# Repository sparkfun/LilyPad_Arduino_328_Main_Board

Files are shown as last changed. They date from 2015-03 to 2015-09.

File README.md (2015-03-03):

SparkFun LilyPad Arduino 328 Main Board
=======================================
SparkFun LilyPad Arduino 328 Main Board

[*SparkFun LilyPad Arduino 328 Main Board
 (DEV-09266)*](https://www.sparkfun.com/products/9266)

This is LilyPad Arduino - the main board consisting of an ATmega328 with the Arduino bootloader and a minimum number of external components to keep it as small (and as simple) as possible. Board will run from 2V to 5V. 

Repository Contents
-------------------

* **/Hardware** - All Eagle design files (.brd, .sch)
License Information
-------------------
The hardware is released under [Creative Commons ShareAlike 4.0 International](https://creativecommons.org/licenses/by-sa/4.0/).

Distributed as-is; no warranty is given.

_A portion of this sale is given back to Dr. Leah Buechley for continued development and education of e-textiles and also to Arduino LLC to help fund continued development of new tools and new IDE features._

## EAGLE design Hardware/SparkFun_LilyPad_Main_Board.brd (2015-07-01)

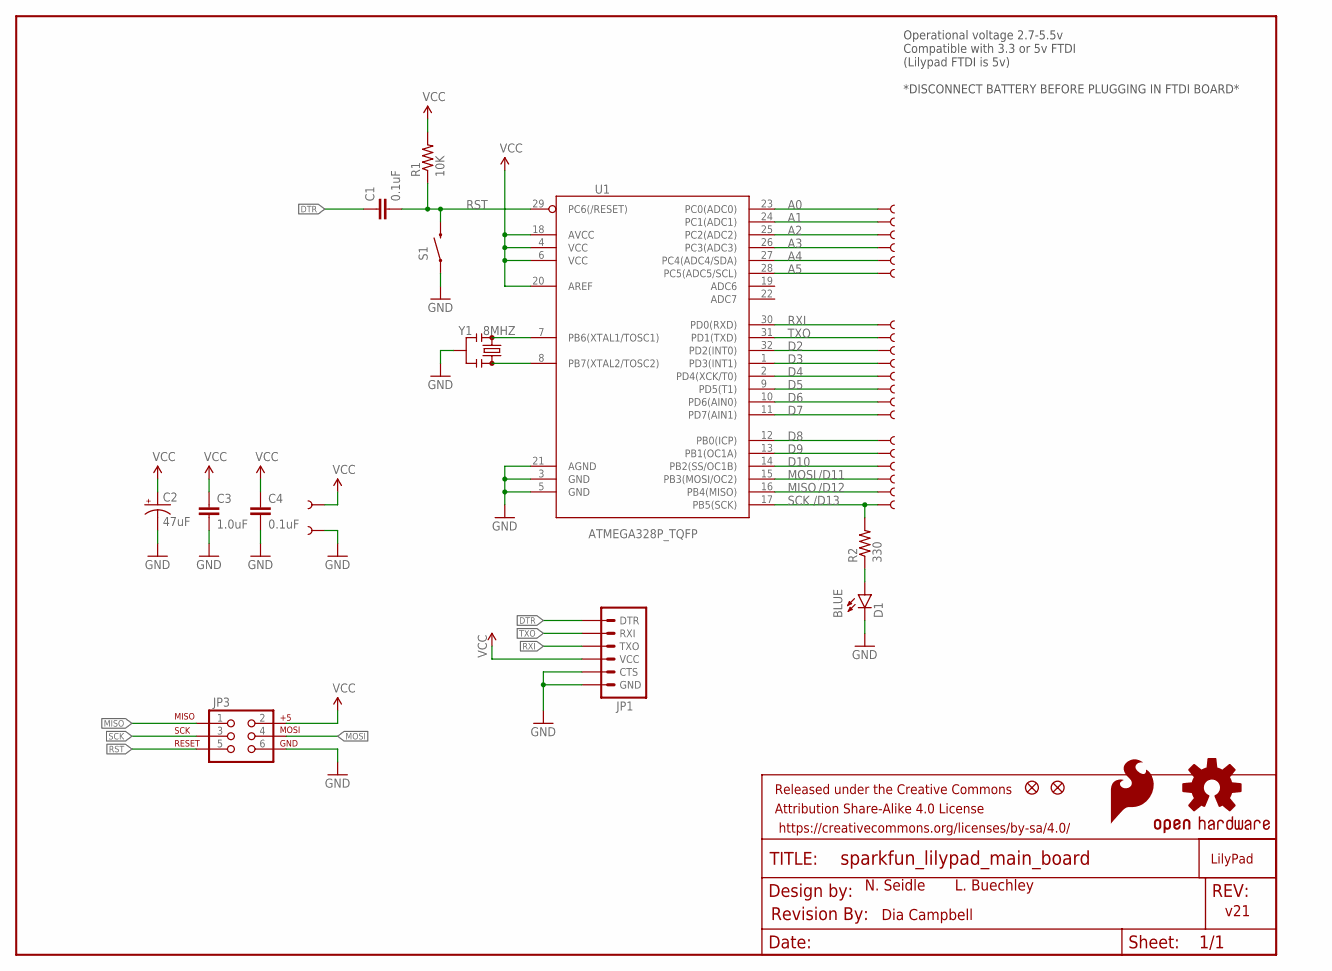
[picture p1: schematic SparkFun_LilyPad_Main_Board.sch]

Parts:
$0000003: LOGO-LPLPA; LOGO-LPA
C1, C4: 0.1uF; 0603-CAP
C2: 47uF; EIA3528
C3: 1.0uF; 0603-CAP
D1: BLUE; LED-0603
FID1, FID2: FIDUCIALUFIDUCIAL; MICRO-FIDUCIAL
FRAME1: FRAME-LETTER; CREATIVE_COMMONS
GND: SEWTAP9; PETAL-LONG-1-2SIDE
JP1: ARDUINO_SERIAL_PROGRAMSMD; 1X06-SMD
JP3: FEMALE 2x3; 2X3-NS
LOGO1: SFE_LOGO_FLAME.3COP; SFE_LOGO_FLAME_COPPER_.3
LOGO2: OSHW-LOGO-COPPERM; OSHW-LOGO-M
R1: 10K; 0603-RES
R2: 330; 0603-RES
S1: SWITCH-MOMENTARY-2SMD-REDUNDANT; TACTILE-SWITCH-SMD
U1: ATMEGA328P_TQFP; TQFP32-08
U$1, U$2, U$3, U$4, U$5, U$6, U$7, U$8, U$9, U$10, U$11, U$12, U$13, U$14, U$15, U$16, U$17, U$18, U$19, U$20, U$21: SEWTAP9; PETAL-LONG-1-2SIDE
U$22: REVISION
Y1: 8MHZ; RESONATOR-SMD

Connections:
A0: U1.23 (PC0(ADC0)), U$1.1
A1: U1.24 (PC1(ADC1)), U$2.1
A2: U1.25 (PC2(ADC2)), U$3.1
A3: U1.26 (PC3(ADC3)), U$4.1
A4: U1.27 (PC4(ADC4/SDA)), U$5.1
A5: U1.28 (PC5(ADC5/SCL)), U$6.1
D2: U1.32 (PD2(INT0)), U$9.1
D3: U1.1 (PD3(INT1)), U$10.1
D4: U1.2 (PD4(XCK/T0)), U$11.1
D5: U1.9 (PD5(T1)), U$12.1
D6: U1.10 (PD6(AIN0)), U$13.1
D7: U1.11 (PD7(AIN1)), U$14.1
D8: U1.12 (PB0(ICP)), U$15.1
D9: U1.13 (PB1(OC1A)), U$16.1
D10: U1.14 (PB2(SS/OC1B)), U$17.1
DTR: C1.1, JP1.1 (DTR)
GND: C2.C (-), C3.2, C4.2, D1.C, GND.1, JP1.5 (CTS), JP1.6 (GND), JP3.6, S1.1, S1.2 (1), U1.3 (GND), U1.5 (GND), U1.21 (AGND), Y1.2
MISO: JP3.1, U1.16 (PB4(MISO)), U$19.1
MOSI: JP3.4, U1.15 (PB3(MOSI/OC2)), U$18.1
unnamed: U1.7 (PB6(XTAL1/TOSC1)), Y1.1
unnamed: D1.A, R2.1
unnamed: U1.8 (PB7(XTAL2/TOSC2)), Y1.3
RST: C1.2, JP3.5, R1.1, S1.3 (2), S1.4 (2), U1.29 (PC6(/RESET))
RXI: JP1.3 (TXO), U1.30 (PD0(RXD)), U$7.1
SCK: JP3.3, R2.2, U1.17 (PB5(SCK)), U$21.1
TXO: JP1.2 (RXI), U1.31 (PD1(TXD)), U$8.1
VCC: C2.A (+), C3.1, C4.1, JP1.4 (VCC), JP3.2, R1.2, U1.4 (VCC), U1.6 (VCC), U1.18 (AVCC), U1.20 (AREF), U$20.1

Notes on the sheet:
/D11
/D12
/D13
L. Buechley
N. Seidle
Dia Campbell
v21
Operational voltage 2.7-5.5v Compatible with 3.3 or 5v FTDI (Lilypad FTDI is 5v) *DISCONNECT BATTERY BEFORE PLUGGING IN FTDI BOARD*

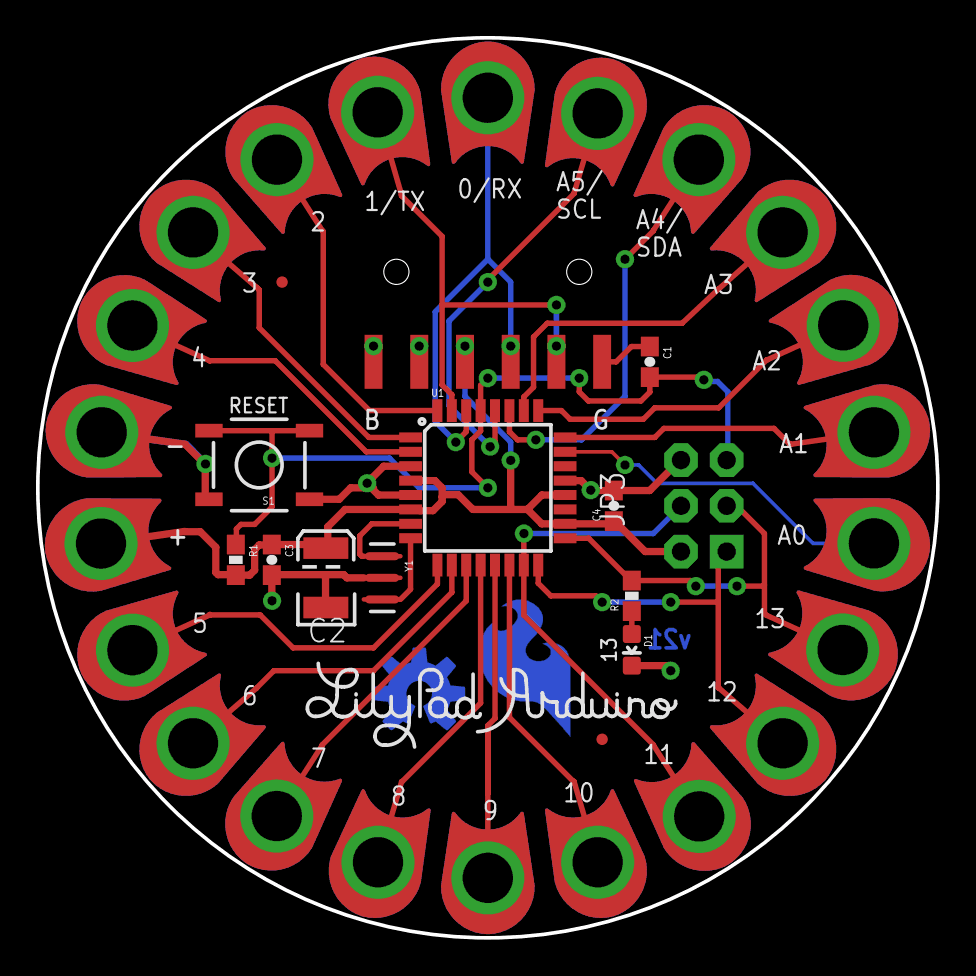
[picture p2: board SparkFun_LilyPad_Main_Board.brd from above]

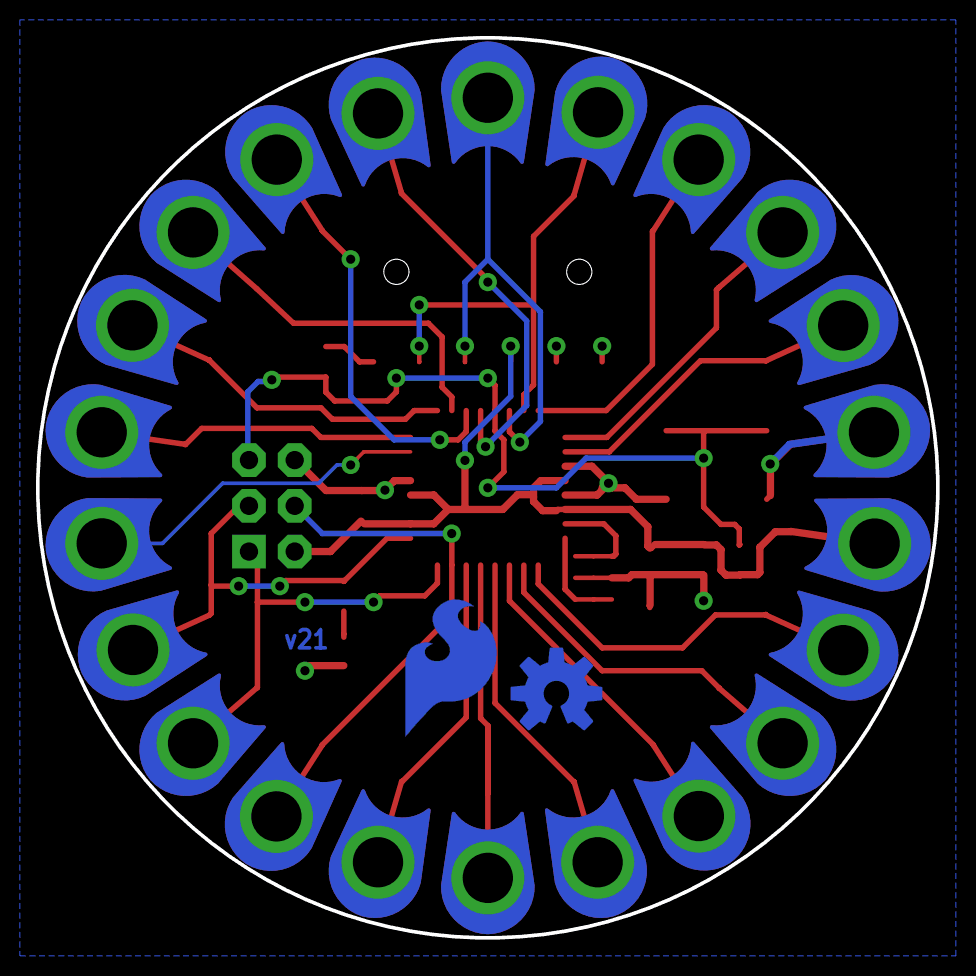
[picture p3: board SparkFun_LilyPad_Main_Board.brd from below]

Board: 2 copper layers, 50.0 x 50.0 mm, 41 parts (2 on the bottom side), 27 nets.

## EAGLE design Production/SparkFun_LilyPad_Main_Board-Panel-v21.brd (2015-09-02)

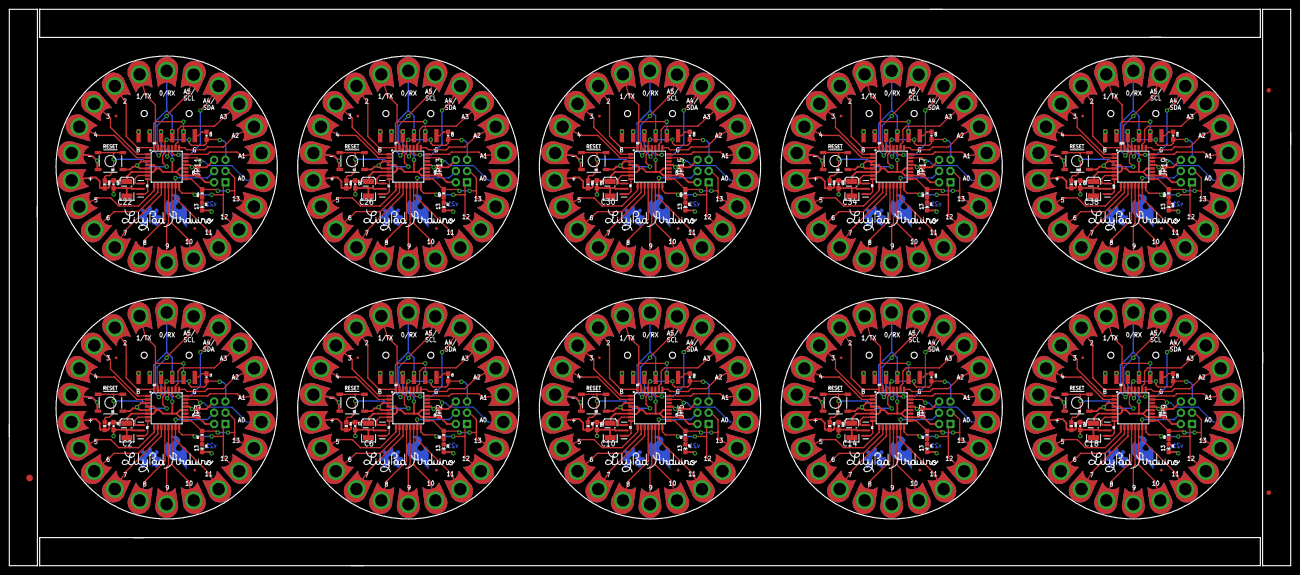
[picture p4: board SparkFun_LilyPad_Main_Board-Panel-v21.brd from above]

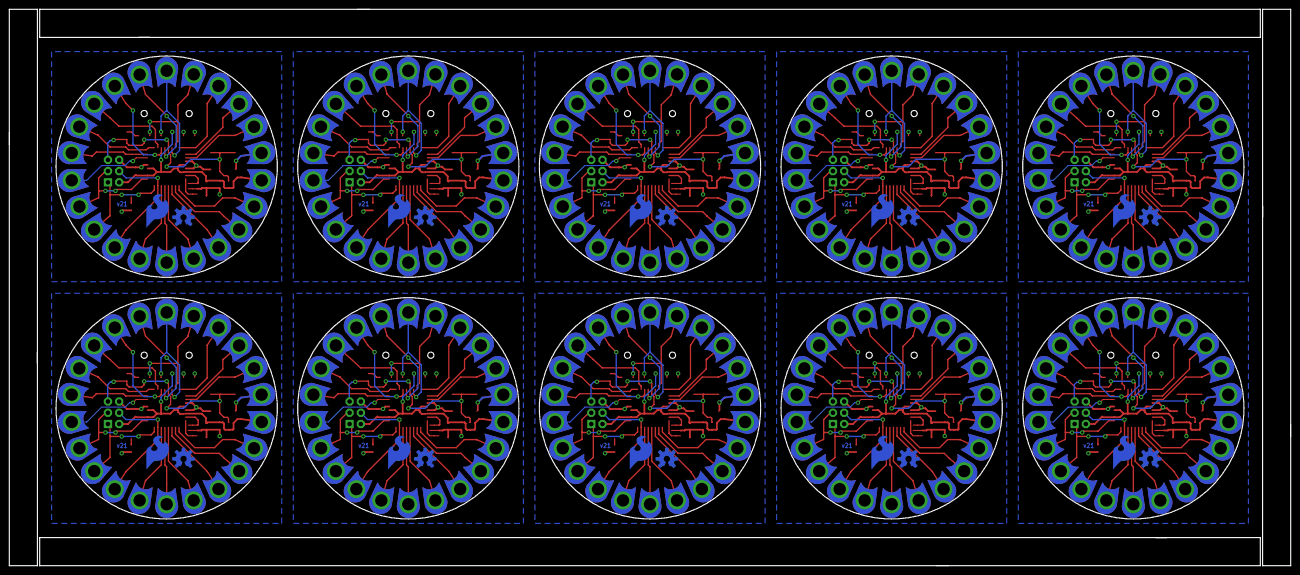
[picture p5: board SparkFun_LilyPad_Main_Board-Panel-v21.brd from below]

Board: 2 copper layers, 289.6 x 125.7 mm, 393 parts (20 on the bottom side), 270 nets.

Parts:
$0000001, $0000002, $0000003, $0000004, $0000005, $0000006, $0000007, $0000008, $0000009, $0000010: LOGO-LPLPA; LOGO-LPA
C1, C4, C5, C8, C9, C12, C13, C16, C17, C20, C21, C24, C25, C28, C29, C32, C33, C36, C37, C40: 0.1uF; 0603-CAP
C2, C6, C10, C14, C18, C22, C26, C30, C34, C38: 47uF; EIA3528
C3, C7, C11, C15, C19, C23, C27, C31, C35, C39: 1.0uF; 0603-CAP
D1, D2, D3, D4, D5, D6, D7, D8, D9, D10: BLUE; LED-0603
E$1: FIDUCIAL-1.5X3
E$7, E$8: FIDUCIAL-1X2
FID1, FID2, FID3, FID4, FID5, FID6, FID7, FID8, FID9, FID10, FID11, FID12, FID13, FID14, FID15, FID16, FID17, FID18, FID19, FID20: FIDUCIALUFIDUCIAL; MICRO-FIDUCIAL
GND, GND1, GND2, GND3, GND4, GND5, GND6, GND7, GND8, GND9: SEWTAP9; PETAL-LONG-1-2SIDE
JP1, JP4, JP6, JP8, JP10, JP12, JP14, JP16, JP18, JP20: 1X06-SMD
JP2, JP3, JP5, JP7, JP9, JP11, JP13, JP15, JP17, JP19: FEMALE 2x3; 2X3-NS
LOGO1, LOGO3, LOGO5, LOGO7, LOGO9, LOGO11, LOGO13, LOGO15, LOGO17, LOGO19: SFE_LOGO_FLAME.3COP; SFE_LOGO_FLAME_COPPER_.3
LOGO2, LOGO4, LOGO6, LOGO8, LOGO10, LOGO12, LOGO14, LOGO16, LOGO18, LOGO20: OSHW-LOGO-COPPERM; OSHW-LOGO-M
R1, R4, R6, R8, R10, R12, R14, R16, R18, R20: 10K; 0603-RES
R2, R3, R5, R7, R9, R11, R13, R15, R17, R19: 330; 0603-RES
S1, S2, S3, S4, S5, S6, S7, S8, S9, S10: SWITCH-MOMENTARY-2SMD-REDUNDANT; TACTILE-SWITCH-SMD
U1, U2, U3, U4, U5, U6, U7, U8, U9, U10: ATMEGA328P_TQFP; TQFP32-08
U$1, U$2, U$3, U$4, U$5, U$6, U$7, U$8, U$9, U$10, U$11, U$12, U$13, U$14, U$15, U$16, U$17, U$18, U$19, U$20, U$21, U$22, U$23, U$24, U$25, U$26, U$27, U$28, U$29, U$30, U$31, U$32, U$33, U$34, U$35, U$36, U$37, U$38, U$39, U$40, U$41, U$42, U$43, U$44, U$45, U$46, U$47, U$48, U$49, U$50, U$51, U$52, U$53, U$54, U$55, U$56, U$57, U$58, U$59, U$60, U$61, U$62, U$63, U$64, U$65, U$66, U$67, U$68, U$69, U$70, U$71, U$72, U$73, U$74, U$75, U$76, U$77, U$78, U$79, U$80, U$81, U$82, U$83, U$84, U$85, U$86, U$87, U$88, U$89, U$90, U$91, U$92, U$93, U$94, U$95, U$96, U$97, U$98, U$99, U$100, U$101, U$102, U$103, U$104, U$105, U$106, U$107, U$108, U$109, U$110, U$111, U$112, U$113, U$114, U$115, U$116, U$117, U$118, U$119, U$120, U$121, U$122, U$123, U$124, U$125, U$126, U$127, U$128, U$129, U$130, U$131, U$132, U$133, U$134, U$135, U$136, U$137, U$138, U$139, U$140, U$141, U$142, U$143, U$144, U$145, U$146, U$147, U$148, U$149, U$150, U$151, U$152, U$153, U$154, U$155, U$156, U$157, U$158, U$159, U$160, U$161, U$162, U$163, U$164, U$165, U$166, U$167, U$168, U$169, U$170, U$171, U$172, U$173, U$174, U$175, U$176, U$177, U$178, U$179, U$180, U$181, U$182, U$183, U$184, U$185, U$186, U$187, U$188, U$189, U$190, U$191, U$192, U$193, U$194, U$195, U$196, U$197, U$198, U$199, U$200, U$201, U$202, U$203, U$204, U$205, U$206, U$207, U$208, U$209, U$210: SEWTAP9; PETAL-LONG-1-2SIDE
Y1, Y2, Y3, Y4, Y5, Y6, Y7, Y8, Y9, Y10: 8MHZ; RESONATOR-SMD

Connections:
A0: U1.23, U$1.1
A1: U1.24, U$2.1
A2: U1.25, U$3.1
A3: U1.26, U$4.1
A4: U1.27, U$5.1
A5: U1.28, U$6.1
A6: U2.23, U$42.1
A7: U2.24, U$22.1
A8: U2.25, U$23.1
A9: U2.26, U$24.1
A10: U2.27, U$25.1
A11: U2.28, U$26.1
A12: U3.23, U$63.1
A13: U3.24, U$43.1
A14: U3.25, U$44.1
A15: U3.26, U$45.1
A16: U3.27, U$46.1
A17: U3.28, U$47.1
A18: U4.23, U$84.1
A19: U4.24, U$64.1
A20: U4.25, U$65.1
A21: U4.26, U$66.1
A22: U4.27, U$67.1
A23: U4.28, U$68.1
A24: U5.23, U$105.1
A25: U5.24, U$85.1
A26: U5.25, U$86.1
A27: U5.26, U$87.1
A28: U5.27, U$88.1
A29: U5.28, U$89.1
A30: U6.23, U$126.1
A31: U6.24, U$106.1
A32: U6.25, U$107.1
A33: U6.26, U$108.1
A34: U6.27, U$109.1
A35: U6.28, U$110.1
A36: U7.23, U$147.1
A37: U7.24, U$127.1
A38: U7.25, U$128.1
A39: U7.26, U$129.1
A40: U7.27, U$130.1
A41: U7.28, U$131.1
A42: U8.23, U$168.1
A43: U8.24, U$148.1
A44: U8.25, U$149.1
A45: U8.26, U$150.1
A46: U8.27, U$151.1
A47: U8.28, U$152.1
A48: U9.23, U$189.1
A49: U9.24, U$169.1
A50: U9.25, U$170.1
A51: U9.26, U$171.1
A52: U9.27, U$172.1
A53: U9.28, U$173.1
A54: U10.23, U$210.1
A55: U10.24, U$190.1
A56: U10.25, U$191.1
A57: U10.26, U$192.1
A58: U10.27, U$193.1
A59: U10.28, U$194.1
D1: U2.32, U$37.1
D2: U1.32, U$9.1
D3: U1.1, U$10.1
D4: U1.2, U$11.1
D5: U1.9, U$12.1
D6: U1.10, U$13.1
D7: U1.11, U$14.1
D8: U1.12, U$15.1
D9: U1.13, U$16.1
D10: U1.14, U$17.1
D11: U2.1, U$36.1
D12: U2.2, U$35.1
D13: U2.9, U$34.1
D14: U2.10, U$33.1
D15: U2.12, U$27.1
D16: U2.14, U$29.1
D17: U2.11, U$40.1
D18: U2.13, U$28.1
D19: U3.32, U$58.1
D20: U3.1, U$57.1
D21: U3.2, U$56.1
D22: U3.9, U$55.1
D23: U3.10, U$54.1
D24: U3.12, U$48.1
D25: U3.14, U$50.1
D26: U3.11, U$61.1
D27: U3.13, U$49.1
D28: U4.32, U$79.1
D29: U4.1, U$78.1
D30: U4.2, U$77.1
D31: U4.9, U$76.1
D32: U4.10, U$75.1
D33: U4.12, U$69.1
D34: U4.14, U$71.1
D35: U4.11, U$82.1
D36: U4.13, U$70.1
D37: U5.32, U$100.1
D38: U5.1, U$99.1
D39: U5.2, U$98.1
D40: U5.9, U$97.1
D41: U5.10, U$96.1
D42: U5.12, U$90.1
D43: U5.14, U$92.1
D44: U5.11, U$103.1
D45: U5.13, U$91.1
D46: U6.32, U$121.1
D47: U6.1, U$120.1
D48: U6.2, U$119.1
D49: U6.9, U$118.1
D50: U6.10, U$117.1
D51: U6.12, U$111.1
D52: U6.14, U$113.1
D53: U6.11, U$124.1
D54: U6.13, U$112.1
D55: U7.32, U$142.1
D56: U7.1, U$141.1
D57: U7.2, U$140.1
D58: U7.9, U$139.1
D59: U7.10, U$138.1
D60: U7.12, U$132.1
D61: U7.14, U$134.1
D62: U7.11, U$145.1
D63: U7.13, U$133.1
D64: U8.32, U$163.1
D65: U8.1, U$162.1
D66: U8.2, U$161.1
D67: U8.9, U$160.1
D68: U8.10, U$159.1
D69: U8.12, U$153.1
D70: U8.14, U$155.1
D71: U8.11, U$166.1
D72: U8.13, U$154.1
D73: U9.32, U$184.1
D74: U9.1, U$183.1
D75: U9.2, U$182.1
D76: U9.9, U$181.1
D77: U9.10, U$180.1
D78: U9.12, U$174.1
D79: U9.14, U$176.1
D80: U9.11, U$187.1
D81: U9.13, U$175.1
D82: U10.32, U$205.1
D83: U10.1, U$204.1
D84: U10.2, U$203.1
D85: U10.9, U$202.1
D86: U10.10, U$201.1
D87: U10.12, U$195.1
D88: U10.14, U$197.1
D89: U10.11, U$208.1
D90: U10.13, U$196.1
DTR: C1.1, JP1.1
DTR1: C8.1, JP4.1
DTR2: C12.1, JP6.1
DTR3: C16.1, JP8.1
DTR4: C20.1, JP10.1
DTR5: C24.1, JP12.1
DTR6: C28.1, JP14.1
DTR7: C32.1, JP16.1
DTR8: C36.1, JP18.1
DTR9: C40.1, JP20.1
GND: C2.C, C3.2, C4.2, D1.C, GND.1, JP1.5, JP1.6, JP3.6, S1.1, S1.2, U1.3, U1.5, U1.21, Y1.2
GND1: C5.2, C6.C, C7.2, D2.C, GND1.1, JP2.6, JP4.5, JP4.6, S2.1, S2.2, U2.3, U2.5, U2.21, Y2.2
GND2: C9.2, C10.C, C11.2, D3.C, GND2.1, JP5.6, JP6.5, JP6.6, S3.1, S3.2, U3.3, U3.5, U3.21, Y3.2
GND3: C13.2, C14.C, C15.2, D4.C, GND3.1, JP7.6, JP8.5, JP8.6, S4.1, S4.2, U4.3, U4.5, U4.21, Y4.2
GND4: C17.2, C18.C, C19.2, D5.C, GND4.1, JP9.6, JP10.5, JP10.6, S5.1, S5.2, U5.3, U5.5, U5.21, Y5.2
GND5: C21.2, C22.C, C23.2, D6.C, GND5.1, JP11.6, JP12.5, JP12.6, S6.1, S6.2, U6.3, U6.5, U6.21, Y6.2
GND6: C25.2, C26.C, C27.2, D7.C, GND6.1, JP13.6, JP14.5, JP14.6, S7.1, S7.2, U7.3, U7.5, U7.21, Y7.2
GND7: C29.2, C30.C, C31.2, D8.C, GND7.1, JP15.6, JP16.5, JP16.6, S8.1, S8.2, U8.3, U8.5, U8.21, Y8.2
GND8: C33.2, C34.C, C35.2, D9.C, GND8.1, JP17.6, JP18.5, JP18.6, S9.1, S9.2, U9.3, U9.5, U9.21, Y9.2
GND9: C37.2, C38.C, C39.2, D10.C, GND9.1, JP19.6, JP20.5, JP20.6, S10.1, S10.2, U10.3, U10.5, U10.21, Y10.2
MISO: JP3.1, U1.16, U$19.1
MISO1: JP2.1, U2.16, U$31.1
MISO2: JP5.1, U3.16, U$52.1
MISO3: JP7.1, U4.16, U$73.1
MISO4: JP9.1, U5.16, U$94.1
MISO5: JP11.1, U6.16, U$115.1
MISO6: JP13.1, U7.16, U$136.1
MISO7: JP15.1, U8.16, U$157.1
MISO8: JP17.1, U9.16, U$178.1
MISO9: JP19.1, U10.16, U$199.1
MOSI: JP3.4, U1.15, U$18.1
MOSI1: JP2.4, U2.15, U$30.1
MOSI2: JP5.4, U3.15, U$51.1
MOSI3: JP7.4, U4.15, U$72.1
MOSI4: JP9.4, U5.15, U$93.1
MOSI5: JP11.4, U6.15, U$114.1
MOSI6: JP13.4, U7.15, U$135.1
MOSI7: JP15.4, U8.15, U$156.1
MOSI8: JP17.4, U9.15, U$177.1
MOSI9: JP19.4, U10.15, U$198.1
unnamed: U1.7, Y1.1
unnamed: D1.A, R2.1
unnamed: U1.8, Y1.3
unnamed: D2.A, R3.1
unnamed: U2.7, Y2.1
unnamed: U2.8, Y2.3
unnamed: D3.A, R5.1
unnamed: U3.7, Y3.1
unnamed: U3.8, Y3.3
unnamed: D4.A, R7.1
unnamed: U4.7, Y4.1
unnamed: U4.8, Y4.3
unnamed: D5.A, R9.1
unnamed: U5.7, Y5.1
unnamed: U5.8, Y5.3
unnamed: D6.A, R11.1
unnamed: U6.7, Y6.1
unnamed: U6.8, Y6.3
unnamed: D7.A, R13.1
unnamed: U7.7, Y7.1
unnamed: U7.8, Y7.3
unnamed: D8.A, R15.1
unnamed: U8.7, Y8.1
unnamed: U8.8, Y8.3
unnamed: D9.A, R17.1
unnamed: U9.7, Y9.1
unnamed: U9.8, Y9.3
unnamed: D10.A, R19.1
unnamed: U10.7, Y10.1
unnamed: U10.8, Y10.3
RST: C1.2, JP3.5, R1.1, S1.3, S1.4, U1.29
RST1: C8.2, JP2.5, R4.1, S2.3, S2.4, U2.29
RST2: C12.2, JP5.5, R6.1, S3.3, S3.4, U3.29
RST3: C16.2, JP7.5, R8.1, S4.3, S4.4, U4.29
RST4: C20.2, JP9.5, R10.1, S5.3, S5.4, U5.29
RST5: C24.2, JP11.5, R12.1, S6.3, S6.4, U6.29
RST6: C28.2, JP13.5, R14.1, S7.3, S7.4, U7.29
RST7: C32.2, JP15.5, R16.1, S8.3, S8.4, U8.29
RST8: C36.2, JP17.5, R18.1, S9.3, S9.4, U9.29
RST9: C40.2, JP19.5, R20.1, S10.3, S10.4, U10.29
RXI: JP1.3, U1.30, U$7.1
RXI1: JP4.3, U2.30, U$39.1
RXI2: JP6.3, U3.30, U$60.1
RXI3: JP8.3, U4.30, U$81.1
RXI4: JP10.3, U5.30, U$102.1
RXI5: JP12.3, U6.30, U$123.1
RXI6: JP14.3, U7.30, U$144.1
RXI7: JP16.3, U8.30, U$165.1
RXI8: JP18.3, U9.30, U$186.1
RXI9: JP20.3, U10.30, U$207.1
SCK: JP3.3, R2.2, U1.17, U$21.1
SCK1: JP2.3, R3.2, U2.17, U$32.1
SCK2: JP5.3, R5.2, U3.17, U$53.1
SCK3: JP7.3, R7.2, U4.17, U$74.1
SCK4: JP9.3, R9.2, U5.17, U$95.1
SCK5: JP11.3, R11.2, U6.17, U$116.1
SCK6: JP13.3, R13.2, U7.17, U$137.1
SCK7: JP15.3, R15.2, U8.17, U$158.1
SCK8: JP17.3, R17.2, U9.17, U$179.1
SCK9: JP19.3, R19.2, U10.17, U$200.1
TXO: JP1.2, U1.31, U$8.1
TXO1: JP4.2, U2.31, U$38.1
TXO2: JP6.2, U3.31, U$59.1
TXO3: JP8.2, U4.31, U$80.1
TXO4: JP10.2, U5.31, U$101.1
TXO5: JP12.2, U6.31, U$122.1
TXO6: JP14.2, U7.31, U$143.1
TXO7: JP16.2, U8.31, U$164.1
TXO8: JP18.2, U9.31, U$185.1
TXO9: JP20.2, U10.31, U$206.1
VCC: C2.A, C3.1, C4.1, JP1.4, JP3.2, R1.2, U1.4, U1.6, U1.18, U1.20, U$20.1
VCC1: C5.1, C6.A, C7.1, JP2.2, JP4.4, R4.2, U2.4, U2.6, U2.18, U2.20, U$41.1
VCC2: C9.1, C10.A, C11.1, JP5.2, JP6.4, R6.2, U3.4, U3.6, U3.18, U3.20, U$62.1
VCC3: C13.1, C14.A, C15.1, JP7.2, JP8.4, R8.2, U4.4, U4.6, U4.18, U4.20, U$83.1
VCC4: C17.1, C18.A, C19.1, JP9.2, JP10.4, R10.2, U5.4, U5.6, U5.18, U5.20, U$104.1
VCC5: C21.1, C22.A, C23.1, JP11.2, JP12.4, R12.2, U6.4, U6.6, U6.18, U6.20, U$125.1
VCC6: C25.1, C26.A, C27.1, JP13.2, JP14.4, R14.2, U7.4, U7.6, U7.18, U7.20, U$146.1
VCC7: C29.1, C30.A, C31.1, JP15.2, JP16.4, R16.2, U8.4, U8.6, U8.18, U8.20, U$167.1
VCC8: C33.1, C34.A, C35.1, JP17.2, JP18.4, R18.2, U9.4, U9.6, U9.18, U9.20, U$188.1
VCC9: C37.1, C38.A, C39.1, JP19.2, JP20.4, R20.2, U10.4, U10.6, U10.18, U10.20, U$209.1

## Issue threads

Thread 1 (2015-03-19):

Design review v21

lewispg228, 2015-03-19:
1) Remove strange GND polygon under reset button

2) Needs a note about proper VCC range in schematic, and possibly a note about must match which FTDI VCC you are using (3.3V or 5V)

3) Route resonator trace off "upper" pad so that it goes outward, and avoids causing a "T" underneath the part.

4) Needs version number in copper

5) Remove "FEMALE 2X3" value on JP3

6) Better placement of name/value on U1 (in schematic)

7) Move vias on FTDI header pads off of the pads, re-route as necessary

8) Increase trace width on GND and VCC to 16 mil.

9) Our new standard for Stat LEDs is Blue, but this could be an exception if it is deemed to much of a pain point to update documentation.

10) Use GND/VCC symbols coming off of JP1.

11) include measures on layer 47 (maybe just the diameter)

12) Needs fiducials

13) I think it would be worth adding a bottom side trace from the "-" pedal to the ground pour to increase the amount of copper connecting to GND. As it is now, there is really only a single 12 mil trace returning all current form the board to GND.

14) Needs note on tdocu about special board thickness

15) add "stat" silk for  stat LED. Maybe lilypad is an exception?

16) Label the reset button with some silk

RobotGirlfriend, 2015-03-26:
1) Done
2) Done
3) Done
4) Done
5) Done
6) Done
7) These were always here (I moved them up the pad a bit, but didn't add them), and probably helping to root down a connector that's likely to get significant stress. Is removing them worth it/necessary?
8) Done
9) EDU doesn't care if we change it, so I'm running it by Leah.
10) Done
11) Done
12) Done
13) Done
14) Done
15) I've added a label, but the LED doesn't actually reflect any 'status' of the board, so I've labeled it "13". It's tied to pin 13 and that's what most educational materials use it for.
16) Done

RobotGirlfriend, 2015-03-31:
Update: Leah has no problem changing the LED to blue, so I went ahead and did that. Also added sparkfun flame and OSHW logo in the copper.

lewispg228, 2015-03-31:
Looks good. thanks!

Two things:

1) we normally put info notes in the schematic on the info layer - you currently have a not on the nets layer.

2) the note about the board thickness is usually in mm and include the color too so "purple 0.08mm"

RobotGirlfriend, 2015-03-31:
Thank you! Fixed! I'll make sure to apply these changes to the tilt and
reed switch boards as well!

  <3 <3 <3

Dia Campbell
Techstyle Specialist
Sparkfun Electronics
303.284.0979 x407

On Tue, Mar 31, 2015 at 3:34 PM, Pete Lewis <notifications@github.com>
wrote:

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

lewispg228, 2015-04-02:
Looks good thanks.

My vote would be to remove the "G" and "B" labeling the FTDI header, but if you or leah or someone else really wants them there, then I guess it's fine.

RobotGirlfriend, 2015-04-02:
I was originally advised to add BLK and GRN, then noticed that it was
previously just B and G. If what you're saying is that it's okay to remove
the silk there entirely, I'd love to!

  <3 <3 <3

Dia Campbell
Techstyle Specialist
Sparkfun Electronics
303.284.0979 x407

On Thu, Apr 2, 2015 at 10:22 AM, Pete Lewis <notifications@github.com>
wrote:

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

lewispg228, 2015-04-02:
Please check in with EDU and CS. If either of them wants them there, then lets keep them.

Closed 2015-04-02.

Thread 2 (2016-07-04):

Do you know if there will be a "Genuino" version of this board?

q2dg, 2016-07-04:
I fear for the future of this board (in terms of distribution and, as a consequenca, of production).
Thanks!

mshorter, 2016-07-05:
Right now this board is produced by Sparkfun and we are staying out of the Arduino war (feels too much like mommy and daddy fighting and the kids being the ones to suffer).  If there comes a point where it is no longer legal for us to sell "Arduino" boards we will most likely just take Arduino out of the name.  Trying to produce 2 versions of a board is not something we really want to do.

q2dg, 2016-07-05:
Ok, perfectly understood. I'll close this issue, then

Closed 2016-07-05.

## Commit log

2015-03-03 Hardware commit and README update
    [SparkFun_LilyPad_Main_Board.brd, SparkFun_LilyPad_Main_Board.sch]
2015-03-13 Committing v21 hardware files
    Updated to 0603, fixed packages, schematic cleanup, and silk updates.
    [SparkFun_LilyPad_Main_Board.brd, SparkFun_LilyPad_Main_Board.sch]
2015-03-26 Updates for QC checklist
    [SparkFun_LilyPad_Main_Board.brd, SparkFun_LilyPad_Main_Board.sch]
2015-03-30 Moving logos to bottom copper, removed some silk
    [SparkFun_LilyPad_Main_Board.brd, SparkFun_LilyPad_Main_Board.sch]
2015-03-30 Made pin 13 LED blue; current standard
    [SparkFun_LilyPad_Main_Board.brd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]
2015-03-31 Moved info on schematic, added board color
    [SparkFun_LilyPad_Main_Board.brd, SparkFun_LilyPad_Main_Board.sch]
2015-04-02 Corrected board thickness
    [SparkFun_LilyPad_Main_Board.brd]
2015-06-25 Silk change to I2C pins
    Leah's request
    [SparkFun_LilyPad_Main_Board.brd]
2015-06-30 Another silk change to I2C pins
    [SparkFun_LilyPad_Main_Board.brd]
2015-07-01 adjust silk for consistency
    [SparkFun_LilyPad_Main_Board.brd]
2015-09-02 created panel v21
    [SparkFun_LilyPad_Main_Board-Panel-v21.brd]

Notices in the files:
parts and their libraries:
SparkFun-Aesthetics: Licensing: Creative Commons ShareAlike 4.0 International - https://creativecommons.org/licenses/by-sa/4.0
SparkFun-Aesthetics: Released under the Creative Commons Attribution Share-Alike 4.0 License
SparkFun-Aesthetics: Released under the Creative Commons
